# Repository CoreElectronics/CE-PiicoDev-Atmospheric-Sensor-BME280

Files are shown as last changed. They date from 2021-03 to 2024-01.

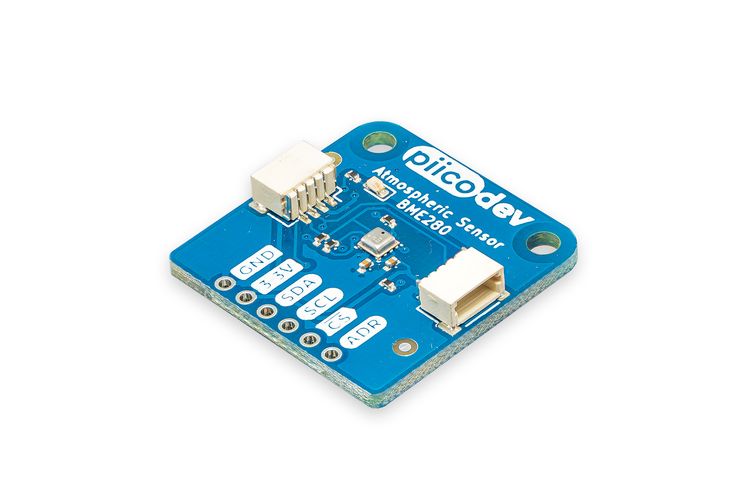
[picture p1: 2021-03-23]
Documents/piicodev-atmospheric-sensor.jpg

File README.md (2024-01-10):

# PiicoDev® Atmospheric Sensor BME280



This is the repo for the Core Electronics [PiicoDev Atmospheric Sensor BME280](https://core-electronics.com.au/catalog/product/view/sku/CE07503).

The PiicoDev® Atmospheric Sensor allows you to easily measure barometric pressure, humidity, and temperature. Use it to build your own weather station or perform experiments. Better still, you can connect to this sensor using our PiicoDev system - no soldering is required to connect the PiicoDev Atmospheric Sensor to other devices in the PiicoDev family.

**Features**

- Measure temperature, pressure and relative humidity
- PiicoDev connector, compatible with Qwiic and STEMMA QT (3.3V only)
- 2.54mm breakout for breadboarding/prototyping
- Manufactured and [supported](https://core-electronics.com.au/contacts/) in Australia by Core Electronics

**Technical Specifications**

- The BME280 measures
  - -40 to +85°C
  - 0 to 100% Relative Humidity
  - 300 to 1100 hPa
- Breakout connector: 3.3V SPI interface, 5V tolerant I2C interface (with pull-up resistors to 3.3V)

# License
This project is open source - please review the LICENSE.md file for further licensing information.

If you have any technical questions, or concerns about licensing, please contact technical support on the [Core Electronics forums](https://forum.core-electronics.com.au/).

# Attribution
The hardware design of this module is influenced by the design from [Sparkfun](https://github.com/sparkfun/Qwiic_Atmospheric_Sensor_Breakout_BME280).

*\"PiicoDev\" and the PiicoDev logo are trademarks of Core Electronics Pty Ltd.*

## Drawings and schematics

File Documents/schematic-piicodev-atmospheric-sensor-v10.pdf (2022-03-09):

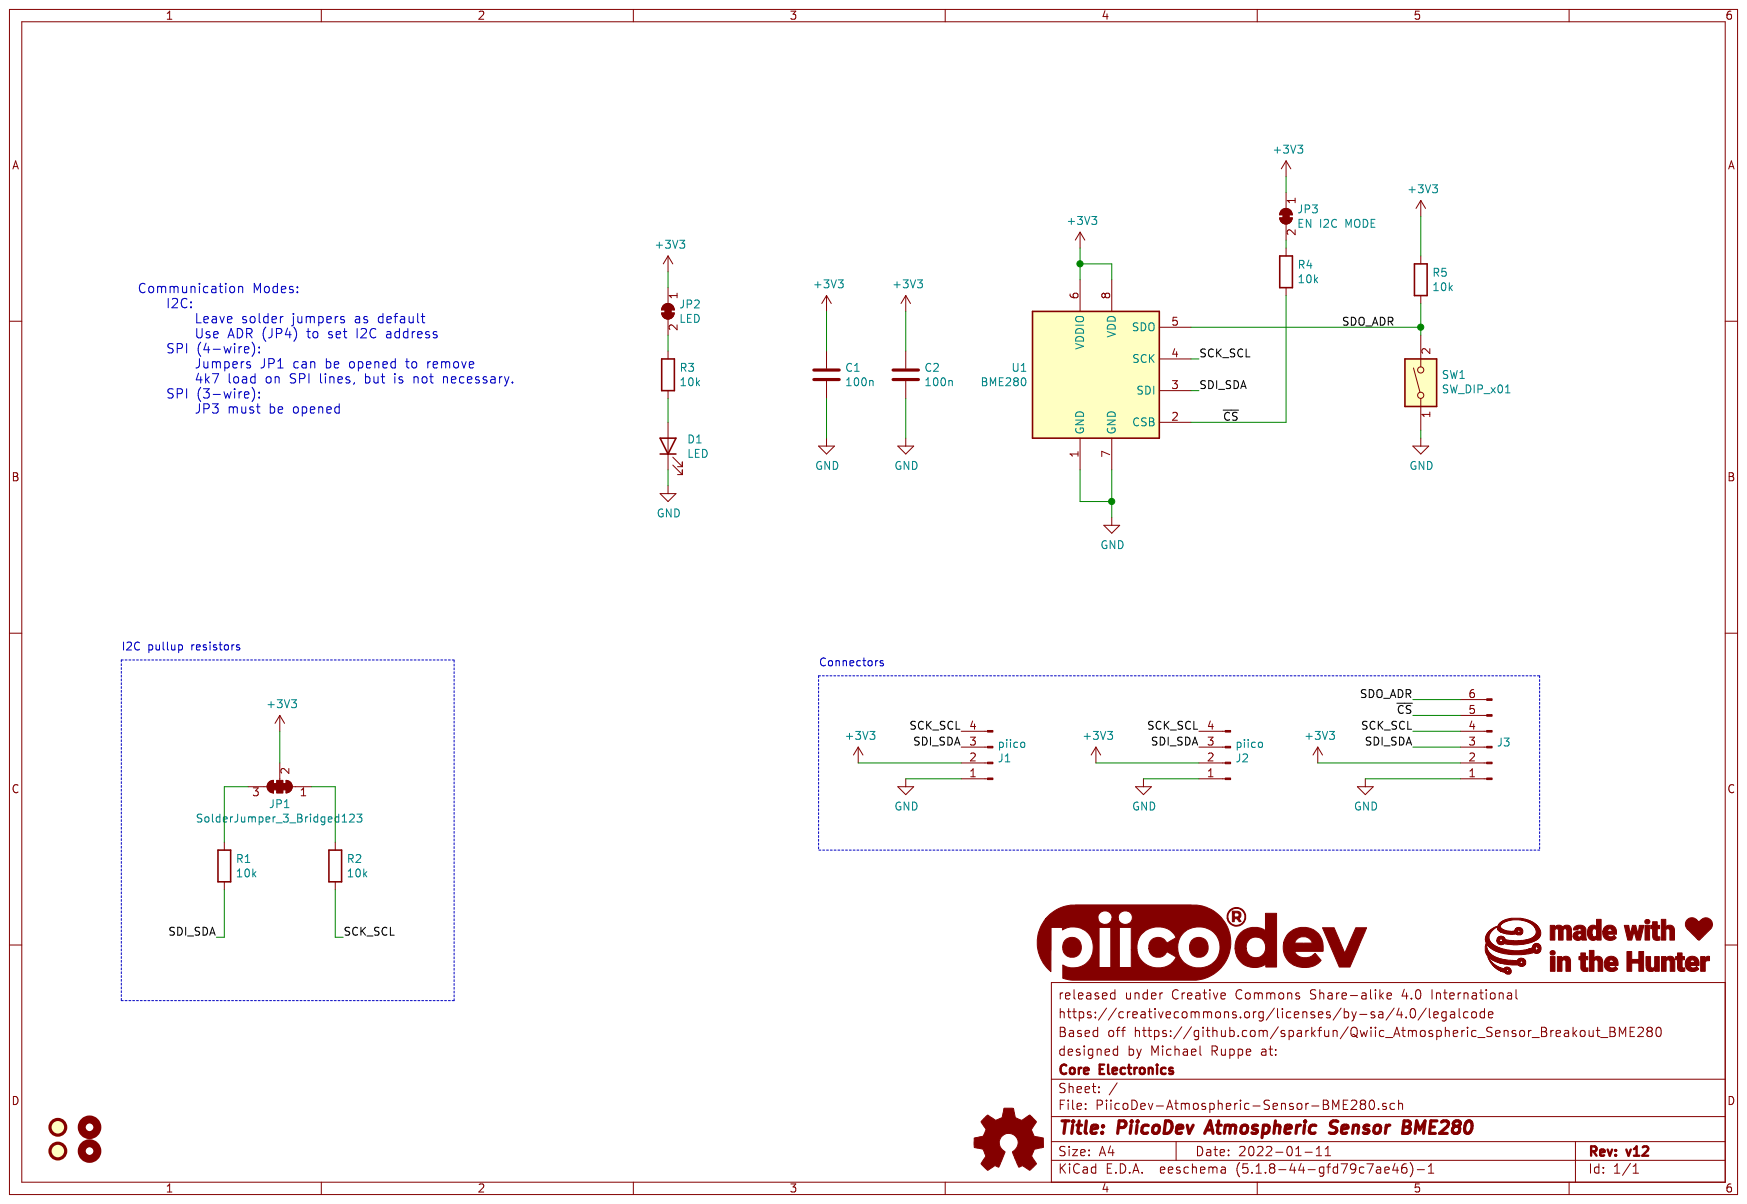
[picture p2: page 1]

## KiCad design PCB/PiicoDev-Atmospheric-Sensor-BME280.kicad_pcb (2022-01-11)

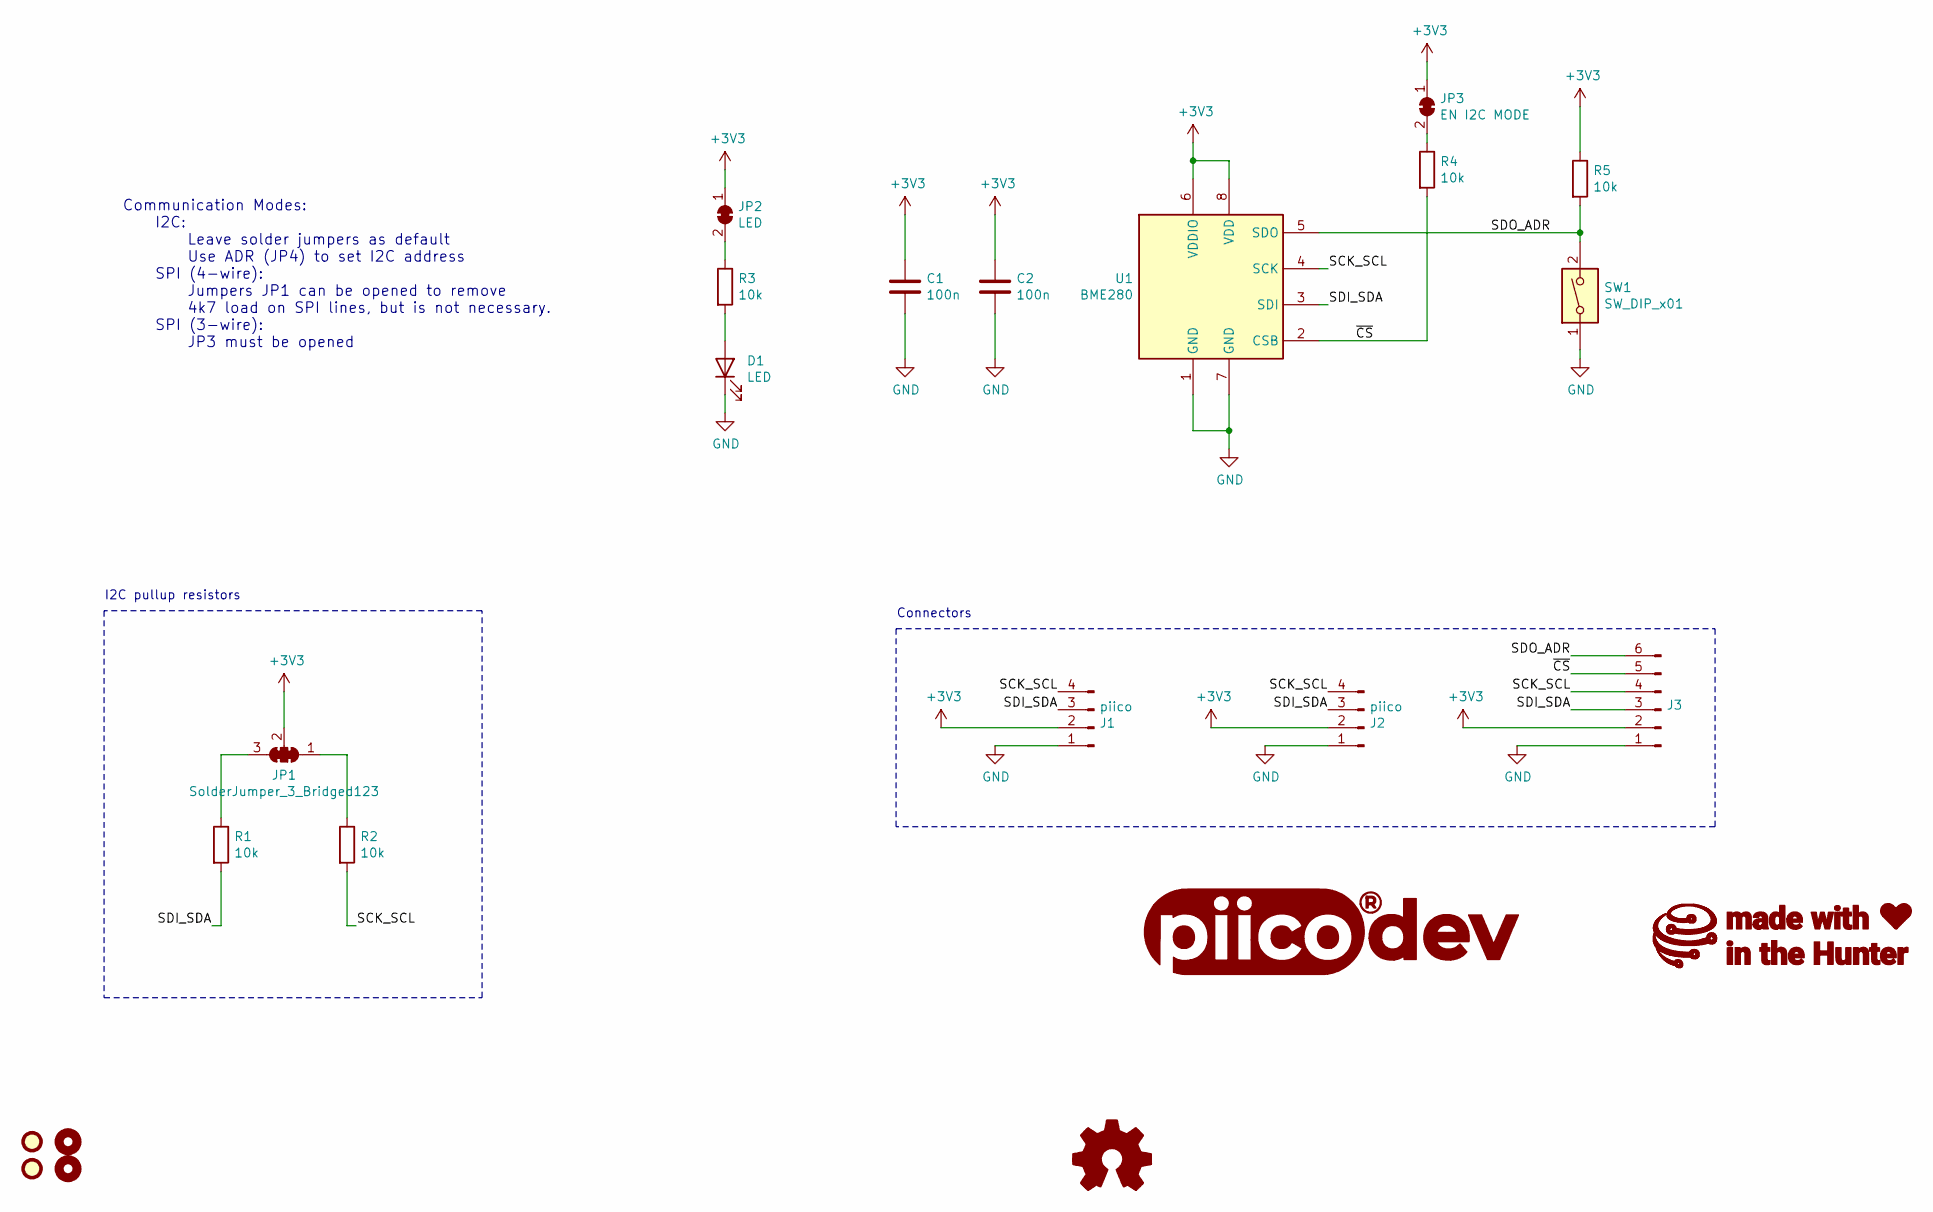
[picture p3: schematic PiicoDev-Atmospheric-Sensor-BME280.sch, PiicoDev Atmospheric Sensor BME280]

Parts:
C1, C2: 100n; C_0402_1005Metric
D1: LED; LED_0603_1608Metric
FID1, FID2: Fiducial; Fiducial_1mm_Mask2mm
G1: LOGO_CoreElectronics_no-text; CoreElectronics_logo_5mm
G2: LOGO_piico; piicodev_logo_14.2x3.4mm
G3: LOGO_made-with-love; piicodev_logo_14.2x3.4mm
H1, H2: MountingHole_2.7mm_M2.5
J1, J2: piico; JST_SH_SM04B-SRSS-TB_1x04-1MP_P1.00mm_Horizontal
J3: PinHeader_1x06_P2.54mm_Vertical_no-silk
JP1: SolderJumper_3_Bridged123; SolderJumper-3_P1.3mm_Closed_RoundedPad1.0x1.5mm_NumberLabe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
JP2: LED; SolderJumper-2_P1.3mm_Bridged_RoundedPad1.0x1.5mm
JP3: EN I2C MODE; SolderJumper-2_P1.3mm_Bridged_RoundedPad1.0x1.5mm
LOGO1: Logo_Open_Hardware_Small; oshw
R1, R2, R3, R4, R5: 10k; R_0402_1005Metric
SW1: SW_DIP_x01; SW_DIP_x01_Slide_CHS-01A1
U1: BME280; Bosch_LGA-8_2.5x2.5mm_P0.65mm_ClockwisePinNumbering

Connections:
+3V3: C1.1, C2.1, J1.2, J2.2, J3.2, JP1.2 (C), JP2.1 (A), JP3.1 (A), R5.1, U1.6 (VDDIO), U1.8 (VDD)
/SCK_SCL: J1.4, J2.4, J3.4, R2.2, U1.4 (SCK)
/SDI_SDA: J1.3, J2.3, J3.3, R1.2, U1.3 (SDI)
/SDO_ADR: J3.6, R5.2, SW1.2, U1.5 (SDO)
/~CS: J3.5, R4.2, U1.2 (CSB)
GND: C1.2, C2.2, D1.1 (K), J1.1, J2.1, J3.1, SW1.1, U1.1 (GND), U1.7 (GND)
unnamed: D1.2 (A), R3.2
unnamed: JP1.1 (A), R2.1
unnamed: JP1.3 (B), R1.1
unnamed: JP2.2 (B), R3.1
unnamed: JP3.2 (B), R4.1

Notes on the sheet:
Connectors
I2C pullup resistors
Communication Modes: I2C: Leave solder jumpers as default Use ADR (JP4) to set I2C address SPI (4-wire): Jumpers JP1 can be opened to remove 4k7 load on SPI lines, but is not necessary. SPI (3-wire): JP3 must be opened

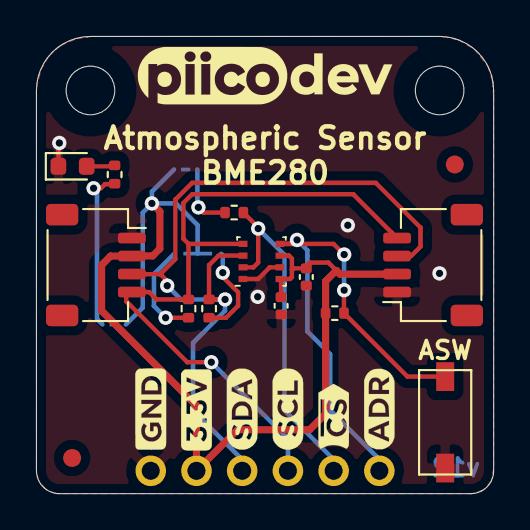
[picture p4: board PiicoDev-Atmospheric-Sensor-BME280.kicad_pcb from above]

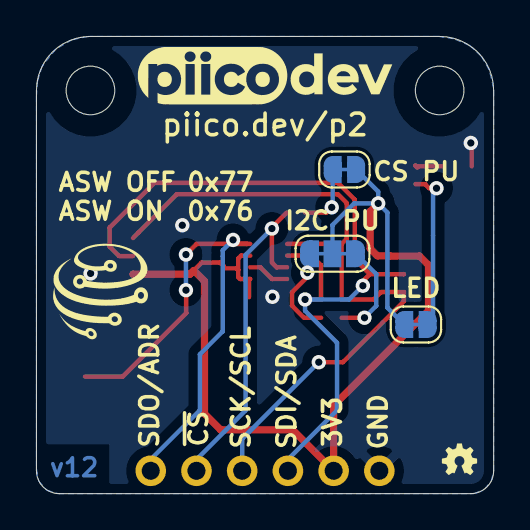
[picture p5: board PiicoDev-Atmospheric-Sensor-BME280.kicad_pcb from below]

Board: 2 copper layers, 25.4 x 25.4 mm, 24 parts (6 on the bottom side), 11 nets.

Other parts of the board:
G1#2: LOGO_CoreElectronics_made-with-love; piicodev_logo_14.2x3.4mm

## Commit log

2021-12-23 v11 Update
    Change resistor values
    Add DIP switch and remove ADR jumper
    Update graphic labels
    Remove solder mask between jumper pads
    Update text formatting
    [PiicoDev-Atmospheric-Sensor-BME280.kicad_pcb, PiicoDev-Atmospheric-Sensor-BME280.sch]
2022-01-06 Update PCB jumpers with thinner cut trace
    [PiicoDev-Atmospheric-Sensor-BME280.kicad_pcb]
2022-01-11 Rename address switch to ASW
    [PiicoDev-Atmospheric-Sensor-BME280.kicad_pcb, PiicoDev-Atmospheric-Sensor-BME280.sch]
2022-03-09 Update schematic to v12

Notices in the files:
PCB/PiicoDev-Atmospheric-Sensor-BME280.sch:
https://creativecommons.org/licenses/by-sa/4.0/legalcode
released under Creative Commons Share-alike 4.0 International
